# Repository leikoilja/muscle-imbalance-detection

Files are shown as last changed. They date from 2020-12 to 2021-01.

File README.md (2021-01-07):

<!-- PROJECT SHIELDS -->
<!--
*** I'm using markdown "reference style" links for readability.
*** Reference links are enclosed in brackets [ ] instead of parentheses ( ).
*** See the bottom of this document for the declaration of the reference variables
*** for contributors-url, forks-url, etc. This is an optional, concise syntax you may use.
*** https://www.markdownguide.org/basic-syntax/#reference-style-links
-->
[][contributors-url]
[][forks-url]
[][stars-url]
[][issues-url]
[][license-url]

<!-- PROJECT LOGO -->
<br />
<p align="center">
  <a href="https://github.com/leikoilja/muscle-imbalance-detection">
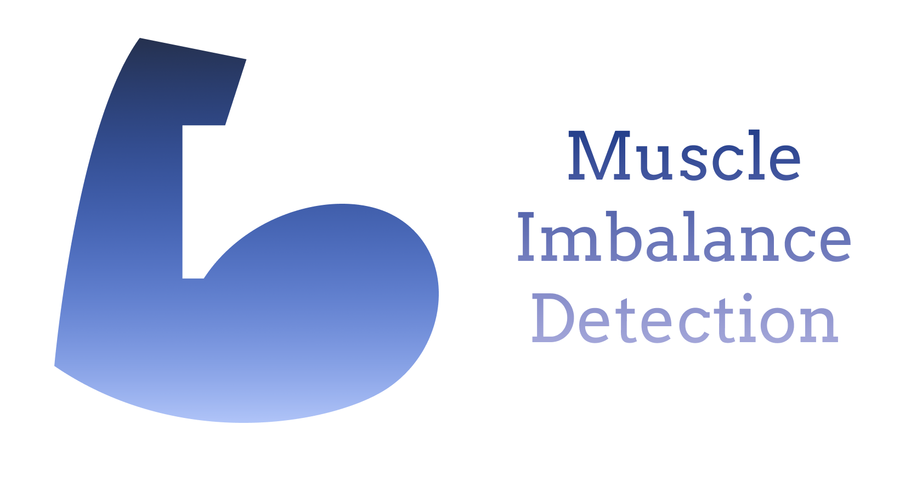
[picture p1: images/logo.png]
    
  </a>

  <h3 align="center">Muscle Imbalance Detection (MID)</h3>

  <p align="center">
    This project was a part of <a href="https://www.kth.se/">KTH</a> University <a href="https://www.kth.se/student/kurser/kurs/HL2032?l=en">HL2032</a> course to create a medical engineering project.
    <br />
    <a href="https://github.com/leikoilja/muscle-imbalance-detection/tree/master/analytics">Analytics</a>
    &
    <a href="https://github.com/leikoilja/muscle-imbalance-detection/tree/master/electronics">Electronics</a>
    &
    <a href="https://github.com/leikoilja/muscle-imbalance-detection/tree/master/mcu">MCU</a>
    &
    <a href="https://github.com/leikoilja/muscle-imbalance-detection/tree/master/mobile_app">Mobile app</a>
  </p>
</p>

<!-- TABLE OF CONTENTS -->
<details open="open">
  <summary>Table of Contents</summary>
  <ol>
    <li>
      <a href="#about-the-project">About The Project</a>
      <ul>
        <li><a href="#design">Design</a></li>
      </ul>
    </li>
    <li>
      <a href="#getting-started">Getting Started</a>
      <ul>
        <li><a href="#prerequisites">Prerequisites</a></li>
      </ul>
    </li>
    <li><a href="#device-demonstration">Demonstration</a></li>
    <li><a href="#contributing">Contributing</a></li>
    <li><a href="#license">License</a></li>
    <li><a href="#acknowledgements">Acknowledgements</a></li>
  </ol>
</details>

<!-- ABOUT THE PROJECT -->
## About The Project
Patients recovering from knee surgery can have inferior long-term mobility if they do not perform specific rehabilitation exercises soon after surgery. Rehabilitation can fail if the patient does not begin it immediately after surgery, or if they do not have good compliance to the treatment plan. We present a device to assist patients and physicians with visualization of the rehabilitation process, to help them make better decisions about how to tailor a recovery plan. The device can display real time muscle activity feedback using reusable fabric electrodes with equivalent sensitivity to a much more expensive commercial sensor, and store and process the data to provide clinical information.

### Design

The system architecture of data communication is shown in figure 1.
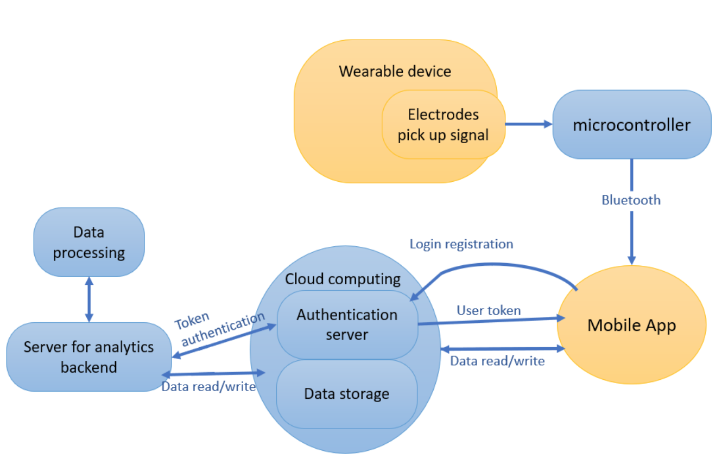
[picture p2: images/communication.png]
Product Name Screen Shot
[](https://example.com)

#### Electrical and Hardware
The system uses pairs of fabric electrodes integrated into a wearable device to detect muscle activity from the patient. A circuit was implemented to amplify and filter the signals before passing them to a microcontroller, and the EMG signal sensitivity can be adjusted using an integrated potentiometer.
The bluetooth module HC-05 is used to communicate between the signal detection circuit and the mobile application. Data sampling rate is currently set to 1KHz.

#### Mobile applicaton
The mobile app was implemented using React Native open-source mobile application framework. It supports user authentication, Bluetooth connectivity for real-time data monitoring, recording of monitored data, and uploading to cloud computing for further processing. It also allows one to see the archive of previous measurements and their corresponding analysis.

#### Cloud computing
The project utilizes Google firebase product which powers up authentication and cloud data storage functionalities. Firebase was chosen due to its robustness and sensitive data safety.
Backend analysis is implemented using python3.7 open source programming language which is mainly used for EMG signal analysis, filtration, and processing with the data collected from the cloud. The dataset we created from various sources used to recognize muscle recovery over time and muscle fatigue level.

<!-- GETTING STARTED -->
## Getting Started

To get started follow the corresponding sections and their READMEs:
<br />
<a href="https://github.com/leikoilja/muscle-imbalance-detection/tree/master/analytics">Analytics</a>
&
<a href="https://github.com/leikoilja/muscle-imbalance-detection/tree/master/electronics">Electronics</a>
&
<a href="https://github.com/leikoilja/muscle-imbalance-detection/tree/master/mcu">MCU</a>
&
<a href="https://github.com/leikoilja/muscle-imbalance-detection/tree/master/mobile_app">Mobile app</a>

### Prerequisites

- Basic electronics and software development knowledge.
- Wearable electrodes for testing. See [this resource](https://github.com/leikoilja/muscle-imbalance-detection/tree/master/electronics/wearble-electrodes) for instructions how to make one.

## Device demonstration
Click to view the video:
Watch the video (https://youtu.be/BWLUeXuKNtg)
Or download the video [here](images/EMG_Knee_Device_Demo_rev2.mp4)

<!-- CONTRIBUTING -->
## Contributing

Contributions are what make the open source community such an amazing place to be learn, inspire, and create. Any contributions you make are **greatly appreciated**.

1. Fork the Project
2. Create your Feature Branch (`git checkout -b feature/AmazingFeature`)
3. Commit your Changes (`git commit -m 'Add some AmazingFeature'`)
4. Push to the Branch (`git push origin feature/AmazingFeature`)
5. Open a Pull Request

<!-- LICENSE -->
## License

Distributed under the MIT License. See `LICENSE` for more information.

<!-- ACKNOWLEDGEMENTS -->
## Acknowledgements
Initial project authors:
* [Katlinkt](https://github.com/Katlinkt)
* [Behname](https://github.com/Behname)
* [sanjayshiva0109](https://github.com/sanjayshiva0109)
* [Vishnu Narayanan](https://github.com/Vishnu1293)
* [Ilja Leiko](https://github.com/leikoilja)

<!-- MARKDOWN LINKS & IMAGES -->
<!-- https://www.markdownguide.org/basic-syntax/#reference-style-links -->
[contributors-shield]: https://img.shields.io/github/contributors/leikoilja/muscle-imbalance-detection
[contributors-url]: https://github.com/leikoilja/muscle-imbalance-detection/graphs/contributors
[forks-shield]: https://img.shields.io/github/forks/leikoilja/muscle-imbalance-detection
[forks-url]: https://github.com/leikoilja/muscle-imbalance-detection/network/members
[stars-shield]: https://img.shields.io/github/stars/leikoilja/muscle-imbalance-detection
[stars-url]: https://github.com/leikoilja/muscle-imbalance-detection/stargazers
[issues-shield]: https://img.shields.io/github/issues/leikoilja/muscle-imbalance-detection
[issues-url]: https://github.com/leikoilja/muscle-imbalance-detection/issues
[license-shield]: https://img.shields.io/github/license/leikoilja/muscle-imbalance-detection
[license-url]: https://github.com/leikoilja/muscle-imbalance-detection/blob/master/LICENSE
[product-screenshot]: images/screenshot.png
[communication-screenshot]: images/communication.png

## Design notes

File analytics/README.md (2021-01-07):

A Python script for supporting the external loading and processing of biological signals.

Features:
- Signal filtering: low 1Hz, high 300Hz
- Explains tkeo filter, moving average filter, butter-worth filter
- Signal smoothing (comparing with different different smoothing levels)
- Signal rectification
- Detecting muscle activation (burst duration)
- RMS (root mean squre value)
- Muscle fatigue level

## Installation
Use the package manager [pip](https://pip.pypa.io/en/stable/) to install biosignalsnotebooks and required dependencies.
```bash
pip install biosignalsnotebooks
pip install numpy
pip install pandas
pip install matplotlib
pip install firebase-admin
```
Please see [this resource](https://firebase.google.com/docs/firestore/quickstart) on how to setup firebase access to python.

## Usage
```python
import firebase_admin
from firebase_admin import credentials
from firebase_admin import firestore

# Use a service account
cred = credentials.Certificate('<PATH-TO-YOUR-KEY>')  # use your personal key file here
firebase_admin.initialize_app(cred)

db = firestore.client()
```
Data is collected from firebase and stored as a dataframe.
To make it readable in biosignals notebook few changes have to be made by adding channels (see examples).

## Contributing
Pull requests are welcome. For major changes, please open an issue first to discuss what you would like to change.

## Credits
Biosignals [notebooks](https://biosignalspulux.com/learn/notebooks/Categories/Detect/detect_bursts_rev.php).

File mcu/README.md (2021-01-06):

# Arduino microcontroller firmware
It receives a string of data containing 6 digits from OpenBCI or custom designed
electronics board, where first 3 characters represent first analog sensor and
last 3 - second analog sensor correspondingly.
For example a received string `123456` would mean that the first analog sensor
value is `123`, while the second analog sensor value is `456`.

## Requirements
- Arduino IDE
- Arduino Nano
- HC05 Bluetooth module (setup to use `115200` baud-rate)

## How to setup
1. Connect HC05 Bluetooth module to Arduino using jumper wires so RX of
   Bluetooth module is connected to D2 pin of Arduino, while TX of Bluetooth
   module is connected to D3 pin of Arduino.
2. Connect 3.3V(5V) power and GND from Arduino to HC05 Bluetooth module.
3. Open `mcu.ino` file in Arduino IDE, connect Arduino Nano using USB to your
   computer and upload the code.
4. Connect OpenBCI or custom designed circuit board to send data to Arduino
   using Arduino's RX ports correspondingly.
4. You can open Serial Monitor in Arduino IDE to debug what values are sent

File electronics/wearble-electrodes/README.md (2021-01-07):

# How to make wearble electrodes
The wearble device used in this project was created using the [resource](http://www.advancertechnologies.com/2013/03/diy-conductive-fabric-electrodes.html) provided by Advancer Technologies.

Materials:
- soft fabric knee brace
- conductive fabric
- sewing kit (needle, thread, pins)
- wires to attach to circuit
- copper mesh
- soldering iron and solder

The basic steps are as follows:
1. Solder the copper mesh onto the end of the wire that will attach to the electrode. This gives a larger surface area of contact between the wire and the conductive fabric.
2. Cut out pairs of rectangular strips of the conductive fabric (1 pair = measure one muscle). We used strips approximately 2x3cm in size.
3. Take the knee brace, turn it inside out, and pin the fabric electrodes in the place you'd like them to be. Both fabric electrodes should be positioned on the same muscle, at different positions. They will measure the electrical potential difference across the muscle when it is activated.
4. Carefully position the copper mesh between the knee brace and conductive fabric. Sew the conductive fabric into place, which should also hold the copper mesh in place.
5. Repeat step 4 for all electrodes.
6. If possible, weave the electrical wires through the knee brace fabric to help secure them in place. They should all feed back to the location that you want to mount the circuitry (we did this on the side of the thigh).
7. Use a few drops of water to wet the electrode surface before use. This helps improve the contact between the skin and electrode.

<p align="center">
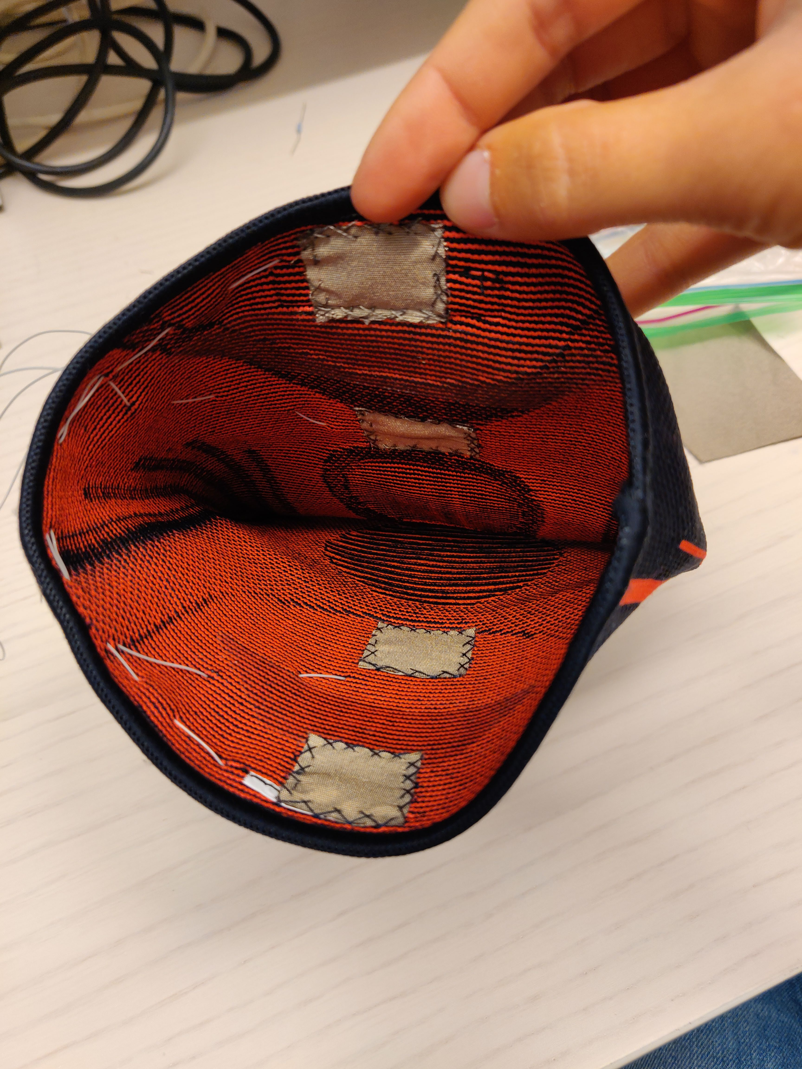
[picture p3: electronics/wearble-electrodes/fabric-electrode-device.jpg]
  
</p>

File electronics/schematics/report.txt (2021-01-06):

Plot file “C:\Users\vishn\Desktop\EMG\emg\Gerber\emg-F_Cu.gbr” created.
Plot file “C:\Users\vishn\Desktop\EMG\emg\Gerber\emg-B_Cu.gbr” created.
Plot file “C:\Users\vishn\Desktop\EMG\emg\Gerber\emg-F_Paste.gbr” created.
Plot file “C:\Users\vishn\Desktop\EMG\emg\Gerber\emg-B_Paste.gbr” created.
Plot file “C:\Users\vishn\Desktop\EMG\emg\Gerber\emg-F_SilkS.gbr” created.
Plot file “C:\Users\vishn\Desktop\EMG\emg\Gerber\emg-B_SilkS.gbr” created.
Plot file “C:\Users\vishn\Desktop\EMG\emg\Gerber\emg-F_Mask.gbr” created.
Plot file “C:\Users\vishn\Desktop\EMG\emg\Gerber\emg-B_Mask.gbr” created.
Plot file “C:\Users\vishn\Desktop\EMG\emg\Gerber\emg-Edge_Cuts.gbr” created.

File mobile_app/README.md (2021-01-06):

# MID (Muscle Imbalance Detection) mobile app

We are using [React Native](https://reactnative.dev/) framework managed by [Expo](https://expo.io/) for mobile development.

## Requirements
- React Native SDK [38.0.2](https://github.com/expo/react-native/archive/sdk-38.0.2.tar.gz)
- Android Studio for android emulator or Xcode for iPhone simulator
- Physical Android or iOS device

## How to setup
1. Install `expo-cli` by following the official [tutorial](https://docs.expo.io/get-started/installation/). Note that you might need to install/upgrade Node.js version as tutorial says.
2. Navigate to the app's root directory and run
```bash
npm start
```
to launch `expo-cli` and follow it's instructions to launch emulator/simulator.

3. To support cloud stored values add your firebase configuration file under `src/firebase/config.tsx` in the
   following format:
```bash
import * as firebase from "firebase";
import "@firebase/auth";
import "@firebase/firestore";

const firebaseConfig = {
  apiKey: "<API-KEY>",
  authDomain: "<APP-NAME>.firebaseapp.com",
  databaseURL: "https://<APP-NAME>.firebaseio.com",
  projectId: "<APP-NAME>",
  storageBucket: "<APP-NAME>.appspot.com",
  messagingSenderId: "<MESSAGING-SENDER-ID>",
  appId: "<APP-ID>",
  measurementId: "<MEASUREMENT-ID>",
};

if (!firebase.apps.length) {
  firebase.initializeApp(firebaseConfig);
  firebase.firestore();
}

export { firebase };
```

## Screenshoots

<p float="left">
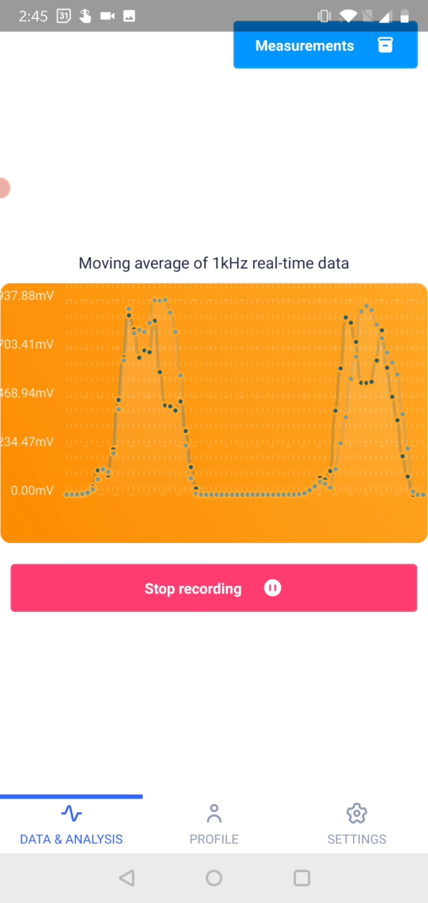
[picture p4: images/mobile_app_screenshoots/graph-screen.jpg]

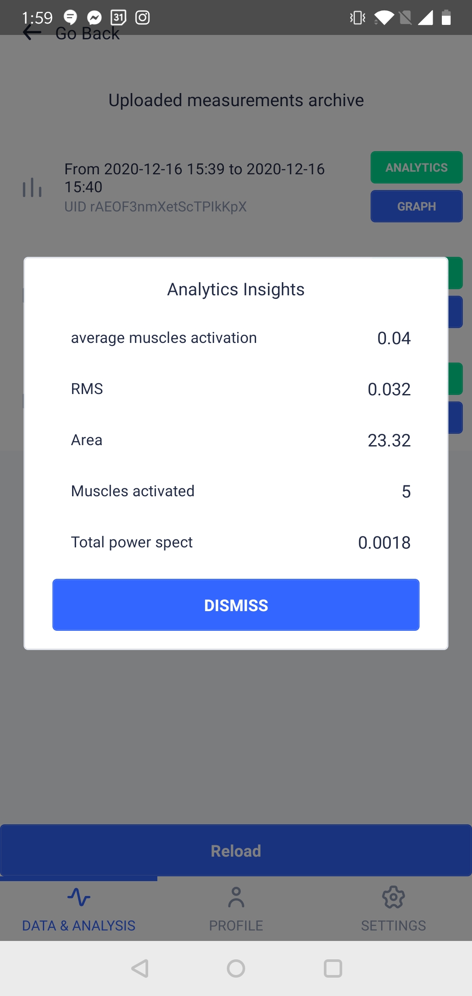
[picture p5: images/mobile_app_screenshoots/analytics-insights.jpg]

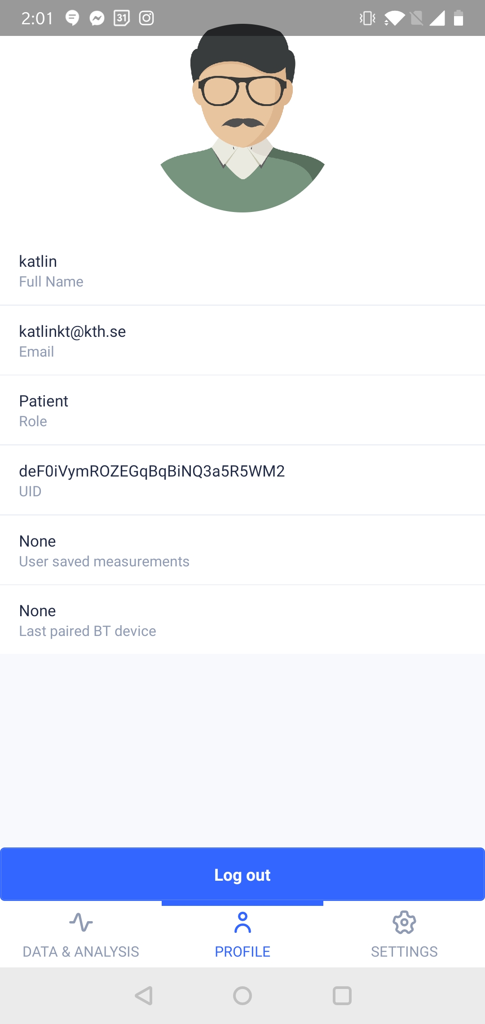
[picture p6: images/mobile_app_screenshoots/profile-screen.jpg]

</p>

## How to contribute
- Write the code
- Open a pull request [here](https://github.com/leikoilja/muscle-imbalance-detection/pulls).

### References
- [React-Native + Redux + Typescript Guide](https://medium.com/@killerchip0/react-native-redux-typescript-guide-f251db03428f)
- [React-Native + Redux + Firebase](https://itnext.io/simple-firebase-redux-integration-in-react-native-32f848deff3a)

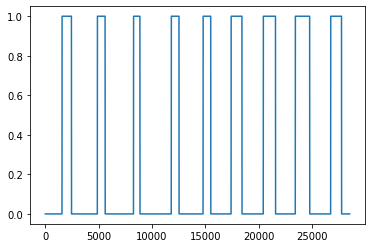
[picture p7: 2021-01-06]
analytics/square wave signal from emg signal.png

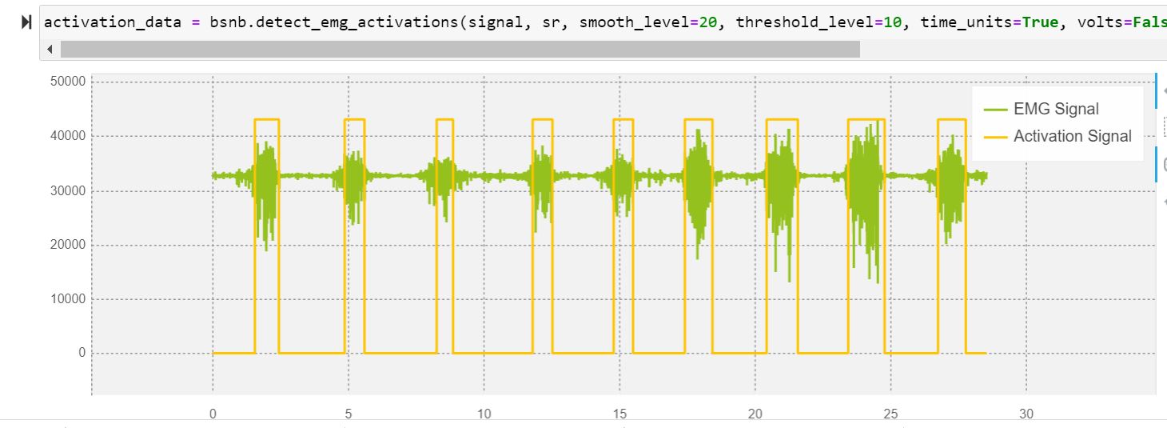
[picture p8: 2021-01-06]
analytics/evet.JPG

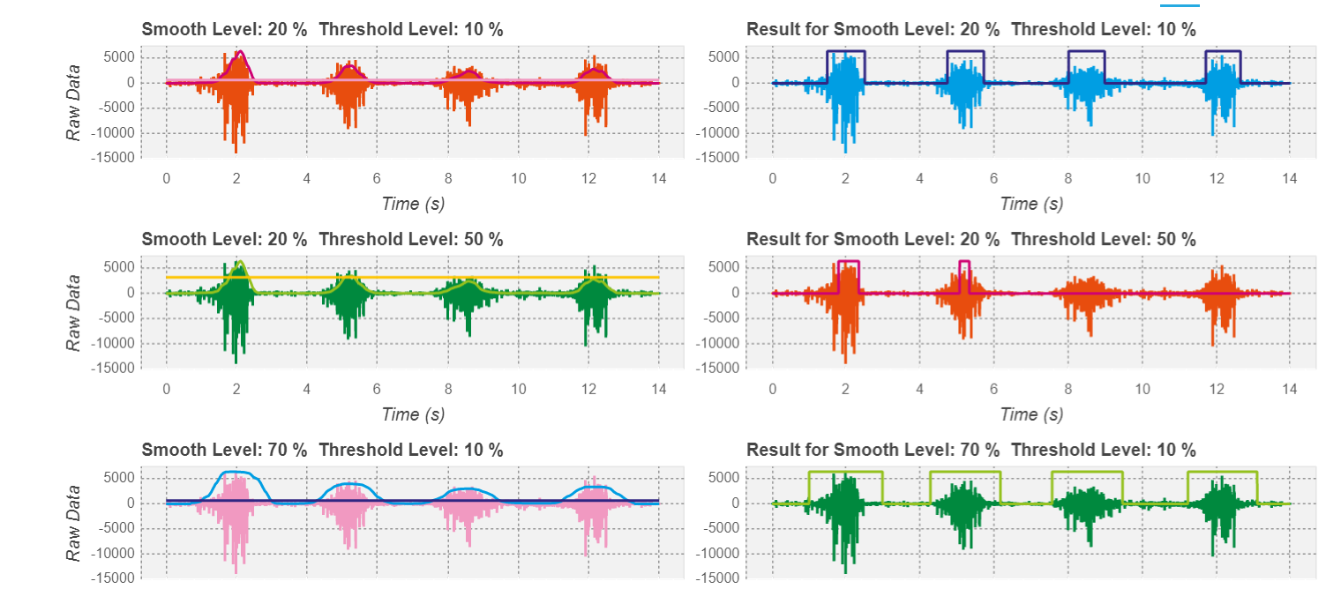
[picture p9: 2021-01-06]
analytics/compare threshold and smooth.PNG

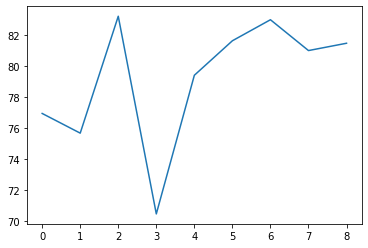
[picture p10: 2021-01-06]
analytics/fatiguee.png

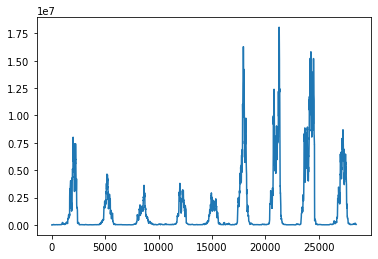
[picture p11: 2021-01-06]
analytics/moving average filter.png

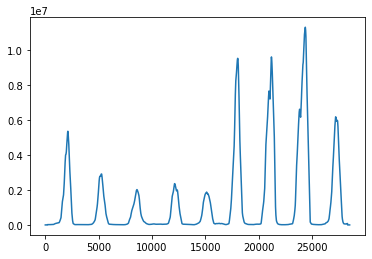
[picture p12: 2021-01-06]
analytics/smoothing signal.png

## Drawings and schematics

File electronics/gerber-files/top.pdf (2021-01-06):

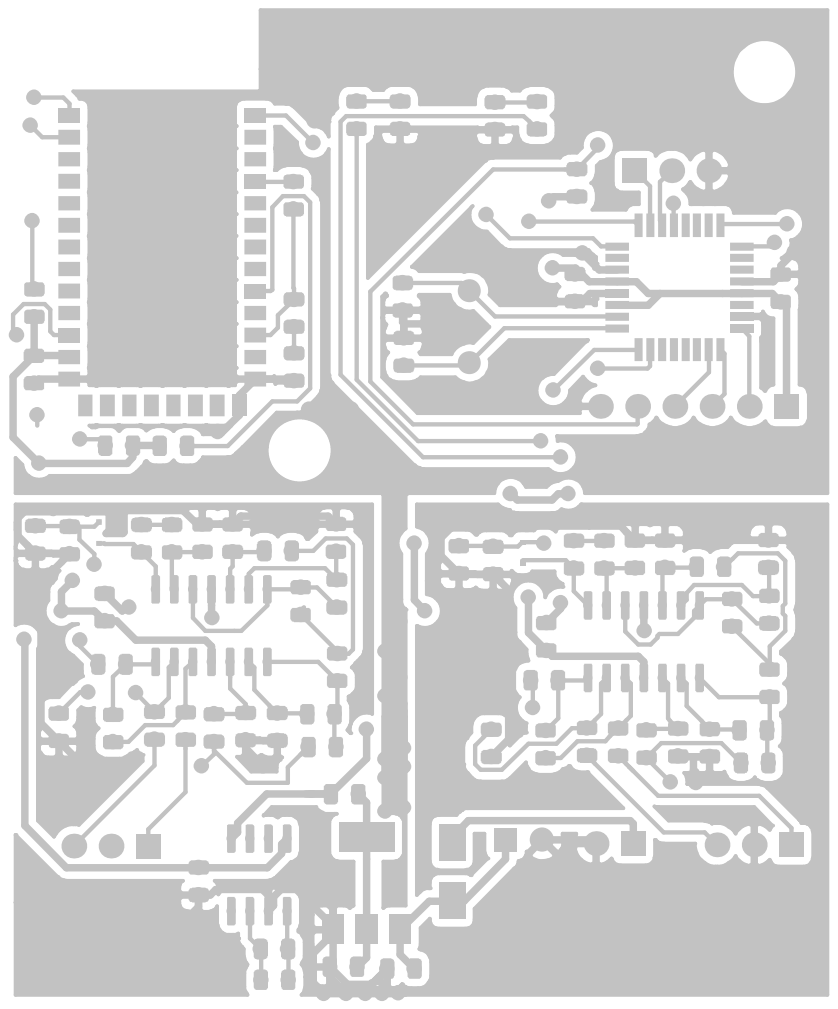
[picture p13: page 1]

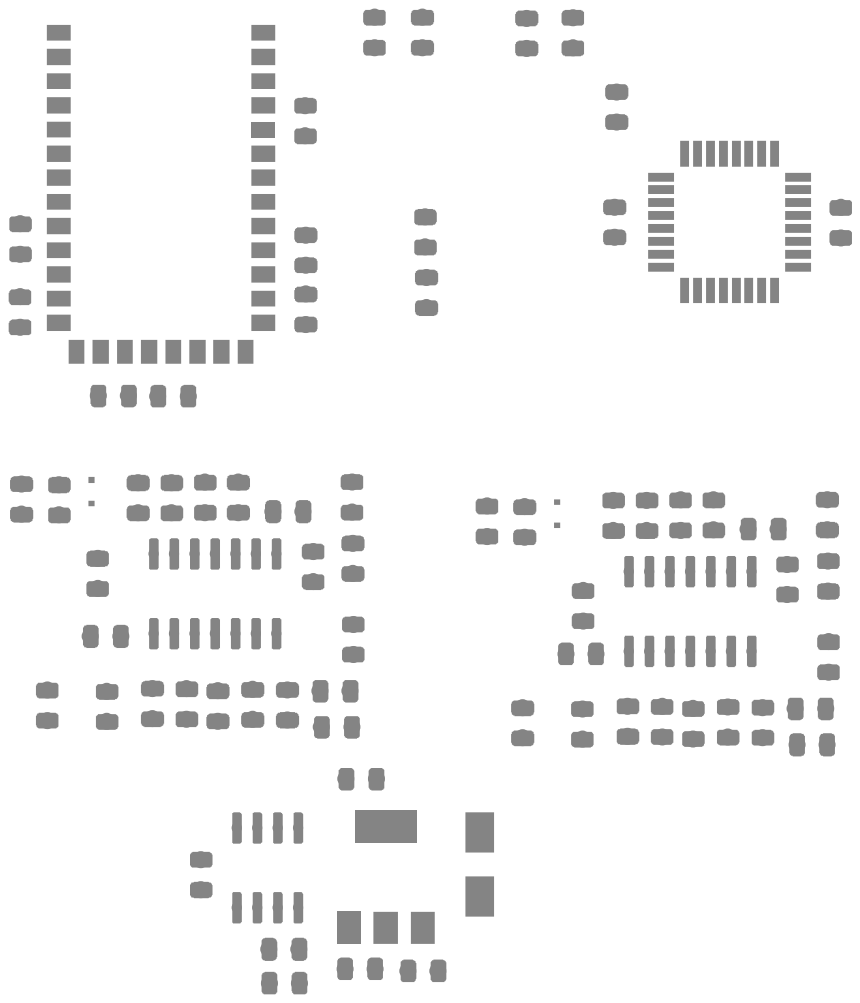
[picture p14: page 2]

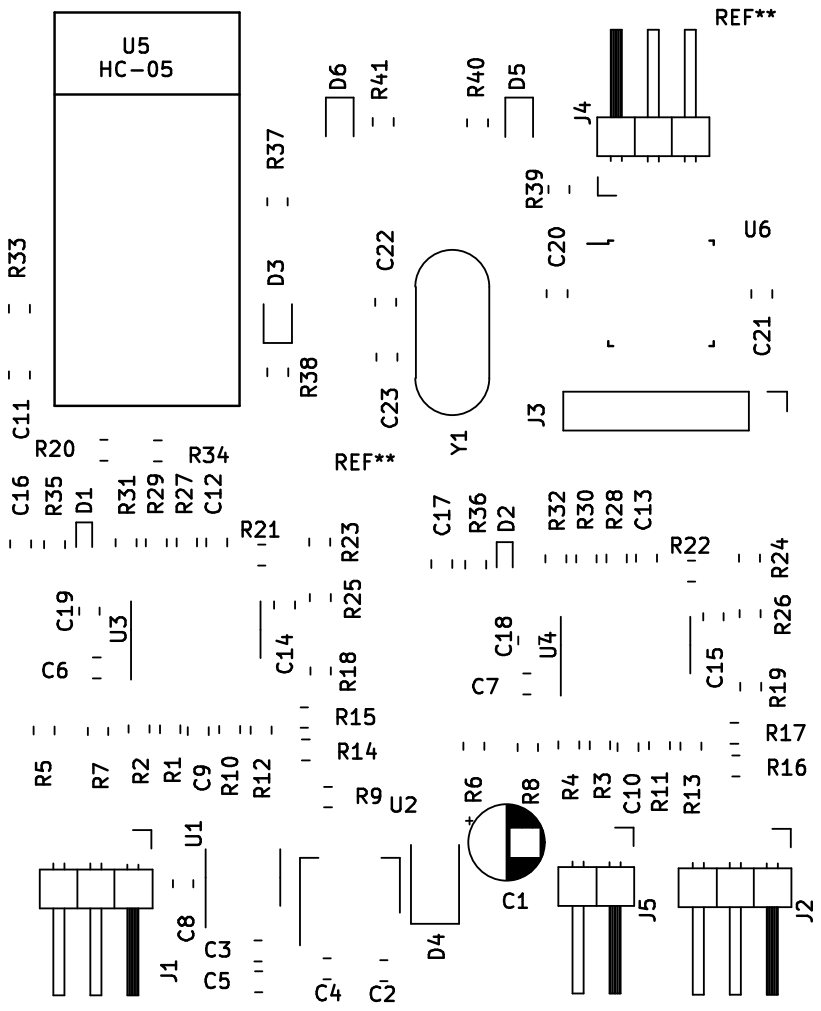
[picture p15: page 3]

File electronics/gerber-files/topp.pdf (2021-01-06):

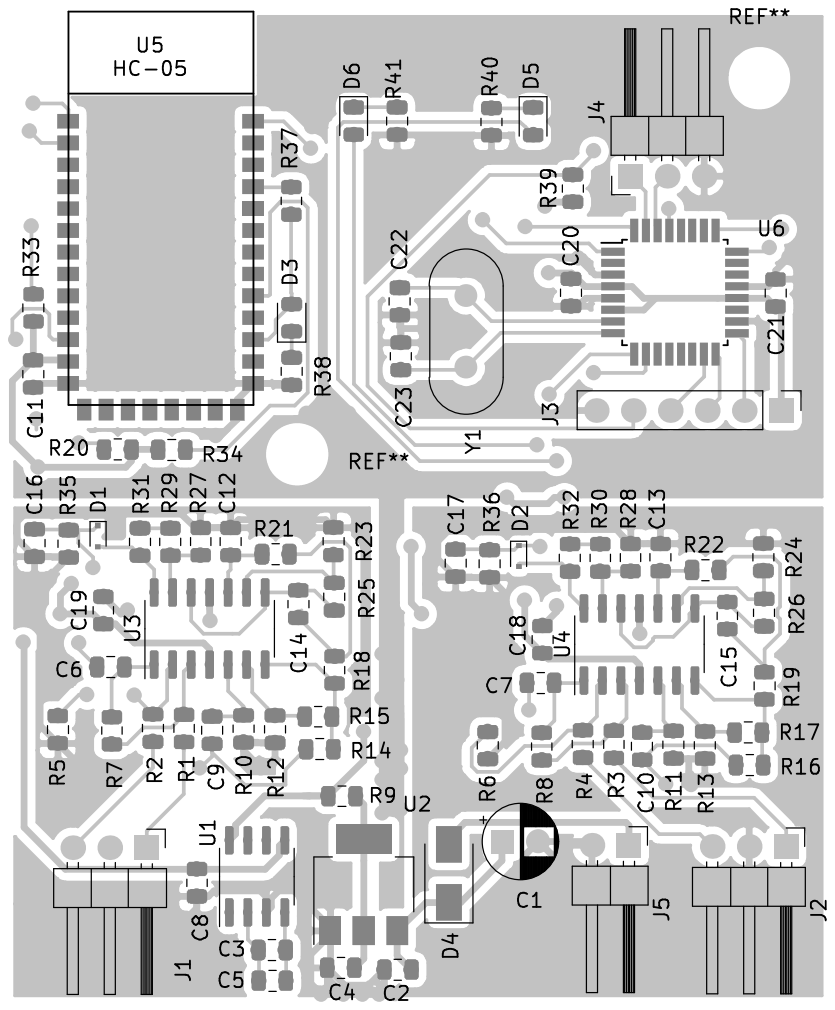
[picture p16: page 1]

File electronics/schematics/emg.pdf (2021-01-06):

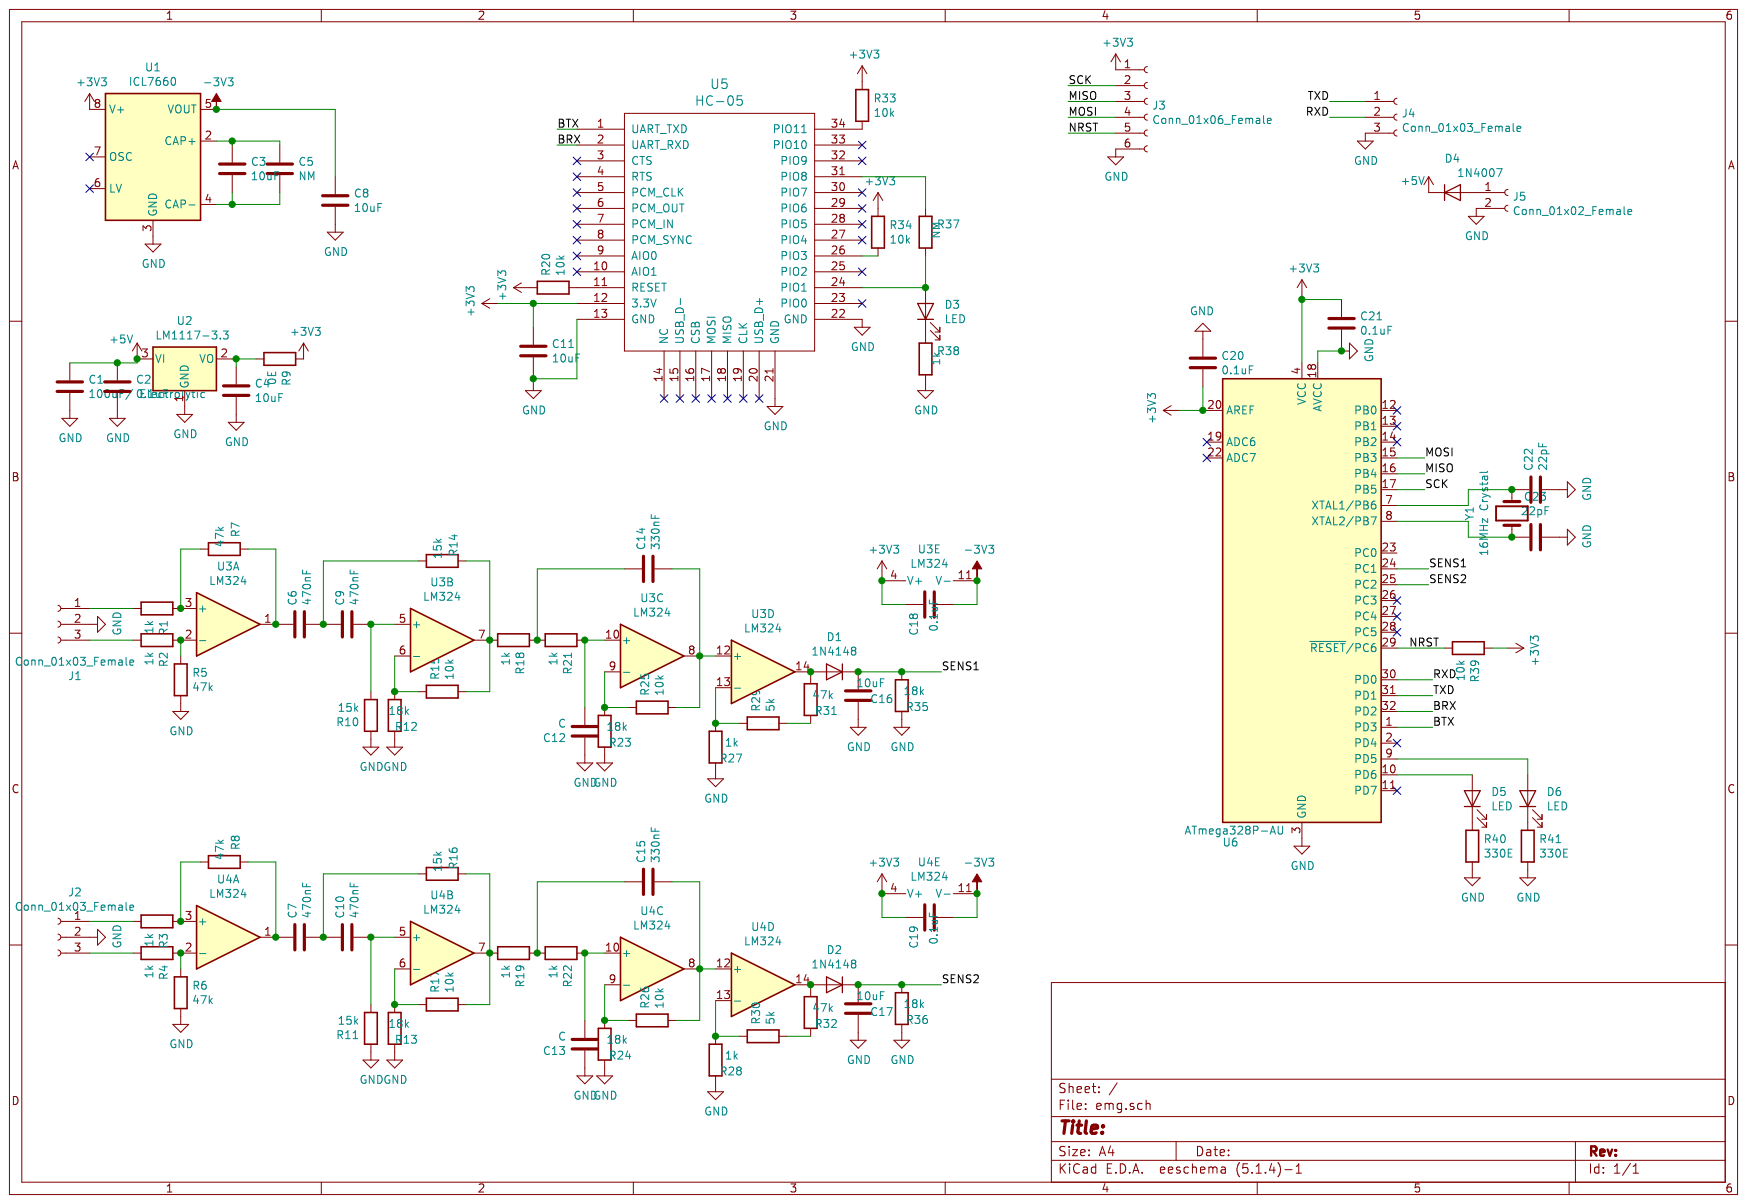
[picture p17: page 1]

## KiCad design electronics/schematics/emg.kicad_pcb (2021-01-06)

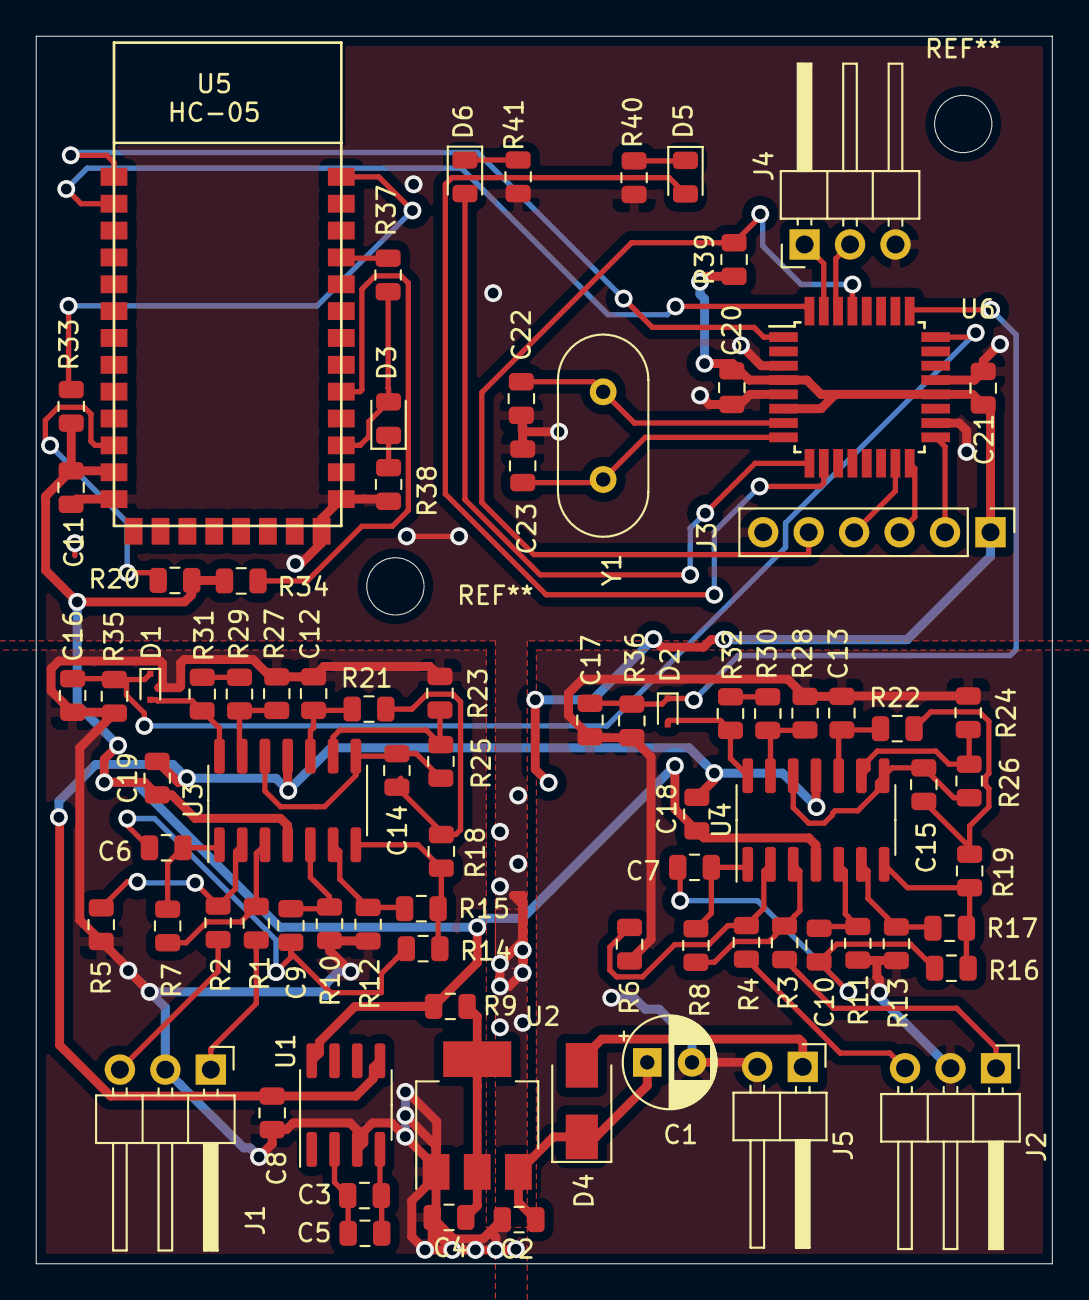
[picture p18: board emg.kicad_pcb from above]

Board: 2 copper layers, 56.8 x 68.6 mm, 82 parts (0 on the bottom side), 62 nets.

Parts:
C1: C; CP_Radial_D5.0mm_P2.50mm
C2, C3, C4, C5, C6, C7, C8, C9, C10, C11, C12, C13, C14, C15, C16, C17, C18, C19, C20, C21, C22, C23: C; C_0805_2012Metric
D1, D2: 1N4148; D_SC-80
D3, D5, D6: LED; LED_0805_2012Metric
D4: 1N4007; D_SMA
J1, J2, J4: Conn_01x03_Female; PinHeader_1x03_P2.54mm_Horizontal
J3: Conn_01x06_Female; PinHeader_1x06_P2.54mm_Vertical
J5: Conn_01x02_Female; PinHeader_1x02_P2.54mm_Horizontal
R1, R2, R3, R4, R5, R6, R7, R8, R9, R10, R11, R12, R13, R14, R15, R16, R17, R18, R19, R20, R21, R22, R23, R24, R25, R26, R27, R28, R29, R30, R31, R32, R33, R34, R35, R36, R37, R38, R39, R40, R41: R; R_0805_2012Metric
U1: ICL7660; SOIC-8_3.9x4.9mm_P1.27mm
U2: LM1117-3.3; SOT-223-3_TabPin2
U3, U4: LM324; SOIC-14_3.9x8.7mm_P1.27mm
U5: HC-05
U6: ATmega328P-AU; TQFP-32_7x7mm_P0.8mm
Y1: Crystal; Crystal_HC18-U_Vertical

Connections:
+3V3: C11.1, C18.1, C19.1, C20.2, C21.1, J3.1, R9.1, R20.1, R33.1, R34.1, R39.1, U1.8, U3.4, U4.4, U5.12, U6.4, U6.6, U6.20
+5V: C1.1, C2.1, D4.1, U2.3
-3V3: C8.1, C18.2, C19.2, U1.5, U3.11, U4.11
/BRX: U5.2, U6.32
/BTX: U5.1, U6.1
/MISO: J3.3, U6.16
/MOSI: J3.4, U6.15
/NRST: J3.5, R39.2, U6.29
/RXD: J4.2, U6.30
/SCK: J3.2, U6.17
/SENS1: C16.2, D1.1, R35.2, U6.24
/SENS2: C17.2, D2.1, R36.2, U6.25
/TXD: J4.1, U6.31
GND: C1.2, C2.2, C4.2, C8.2, C11.2, C12.1, C13.1, C16.1, C17.1, C20.1, C21.2, C22.2, C23.2, J1.2, J2.2, J3.6, J4.3, J5.2, R5.2, R6.2, R10.1, R11.1, R12.1, R13.1, R23.1, R24.1, R27.1, R28.1, R35.1, R36.1, R38.1, R40.2, R41.2, U1.3, U2.1, U5.13, U5.21, U5.22, U6.3, U6.5, U6.18, U6.21
unnamed: C3.1, C5.1, U1.2
unnamed: C3.2, C5.2, U1.4
unnamed: C4.1, R9.2, U2.2
unnamed: C6.1, R7.1, U3.1
unnamed: C6.2, C9.1, R14.2
unnamed: C7.1, R8.1, U4.1
unnamed: C9.2, R10.2, U3.5
unnamed: C7.2, C10.1, R16.2
unnamed: C10.2, R11.2, U4.5
unnamed: C12.2, R21.1, U3.10
unnamed: C13.2, R22.1, U4.10
unnamed: C14.1, R18.1, R21.2
unnamed: C14.2, R25.2, U3.8, U3.12
unnamed: C15.1, R19.1, R22.2
unnamed: C15.2, R26.2, U4.8, U4.12
unnamed: C22.1, U6.7, Y1.2
unnamed: C23.1, U6.8, Y1.1
unnamed: D1.2, R31.2, U3.14
unnamed: D2.2, R32.2, U4.14
unnamed: D3.1, R38.2
unnamed: D3.2, R37.1, U5.24
unnamed: D4.2, J5.1
unnamed: D5.1, R40.1
unnamed: D5.2, U6.10
unnamed: D6.1, R41.1
unnamed: D6.2, U6.9
unnamed: J1.1, R1.2
unnamed: J1.3, R2.2
unnamed: J2.1, R3.2
unnamed: J2.3, R4.2
unnamed: R1.1, R7.2, U3.3
unnamed: R2.1, R5.1, U3.2
unnamed: R3.1, R8.2, U4.3
unnamed: R4.1, R6.1, U4.2
unnamed: R12.2, R15.1, U3.6
unnamed: R13.2, R17.1, U4.6
unnamed: R14.1, R15.2, R18.2, U3.7
unnamed: R16.1, R17.2, R19.2, U4.7
unnamed: R20.2, U5.11
unnamed: R23.2, R25.1, U3.9
unnamed: R24.2, R26.1, U4.9
unnamed: R27.2, R29.1, U3.13
unnamed: R28.2, R30.1, U4.13
unnamed: R29.2, R31.1
unnamed: R30.2, R32.1
unnamed: R33.2, U5.34
unnamed: R34.2, U5.26
unnamed: R37.2, U5.31

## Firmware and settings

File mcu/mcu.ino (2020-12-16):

#include <SoftwareSerial.h>
#include <TimerOne.h>

// Define the data transmit/receive pins in Arduino
#define TxD 2
#define RxD 3

// RX, TX for Bluetooth
SoftwareSerial mySerial(RxD, TxD);

String inData;

void setup() {
    mySerial.begin(115200); // For Bluetooth
    Serial.begin(115200); // For the IDE monitor Tools -> Serial Monitor
}

void sendBTData(String receivedUartData) {
    // Extract necessary sensor values from incoming string
    String firstSensorValue = receivedUartData.substring(2,5);
    String secondSensorValue = receivedUartData.substring(8,11);
    String valueToSend = firstSensorValue + secondSensorValue;
    Serial.print("Arduino Sending: ");
    Serial.println(valueToSend);
    Serial.println("-----");
    mySerial.println(valueToSend);
}

void readUartData() {
    /*
        Read serial transmitted data from OpenBCI string by string from RxD(UART
        receive pin). When end of new line reached - send the data to Bluetooth
        module using TxD(UART transmit pin)
    */
    while (mySerial.available() > 0) {
        char recieved = mySerial.read();
        inData += recieved;
        // Process message when new line character is recieved
        if (recieved == '\n') {
            Serial.print("Arduino Received: ");
            Serial.print(inData);
            sendBTData(inData);
            inData = ""; // Clear recieved buffer
        }
    }
}

void loop() {
  readUartData();
}

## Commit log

2020-10-13 Real time graph auto-connecting to last BT device (#29)
2020-10-15 Better error message when failed to connect to saved device
2020-12-16 Arduino MCU code added; Adding Android gradle memory setting
2020-12-16 Adding clean measur. button and better measurements error handling
2021-01-06 Adding device video and app screenshoots
2021-01-06 Fixing directory structure
    [emg-B_Cu.gbr, emg-B_Mask.gbr, emg-B_Paste.gbr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]
2021-01-06 Adding Arduino MCU Readme
2021-01-07 Moving wearable electrode instructions to README
2021-01-07 Adding a reference to wearable electrodes to the README
